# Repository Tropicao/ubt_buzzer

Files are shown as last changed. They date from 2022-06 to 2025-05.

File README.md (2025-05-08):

# Ultimate Blind Test Buzzer

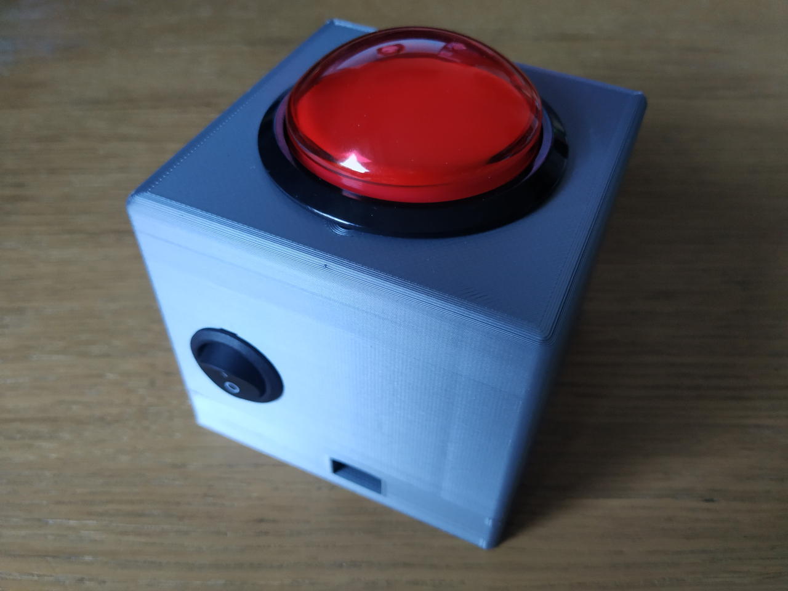
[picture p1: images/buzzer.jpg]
button


## Brief
The Ultimate Blind Test Buzzer (ubt_buzzer) is a companion device for the Ultimate Blind Test. Its main goal
is to provide a basic user interface to allow blind test players to compete.

## Architecture
The buzzer relies on ESP32 with a button connected to it. The buzzer must connect to an access point which offers access to the Ultimate Blind Test server. Once connected, the Ultimate Blind Test server and the buzzer communicate over websocket, for configuration and for statuses (e.g : button pushed)

## Buzzer hardware configuration
* The buzzer is based on ESP32 board with a LiPo charge controller
* A battery can be connected onto the battery controller. Wiring a switch between the two elements allow a simple on/off feature on the buzzer
* The buzzer is meant to be used with a simple push button on GPIO 14 (no need to wire any pull resistor nor RC circuit, button is pulled and debounced by ESP32)

The following layout can be used as an example :
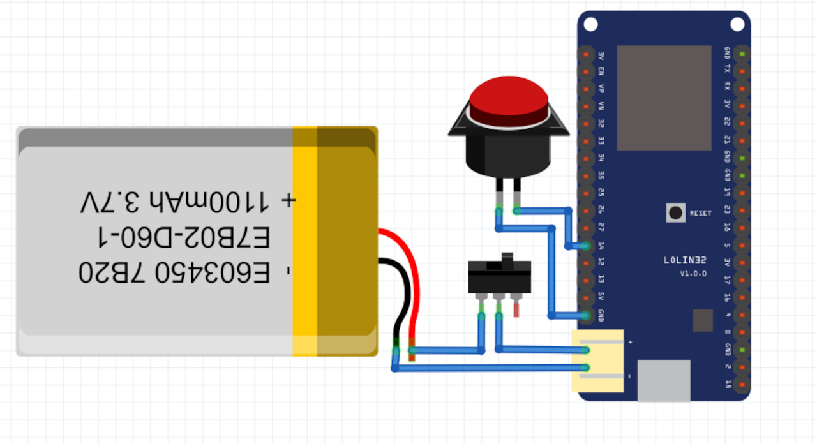
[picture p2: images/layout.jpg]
layout


You can refer to the following components list :
* [AZ-Delivery ESP32 Lolin](https://www.az-delivery.de/fr/products/esp32-lolin-lolin32)
* [Basic Lithium-Polymer battery](https://fr.aliexpress.com/wholesale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), make sure to take a 3.7V battery with connector matching the one on ESP32 board
* [On/Off Switch](https://fr.aliexpress.com/wholesale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)
* [Arcade button](https://fr.aliexpress.com/wholesale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)

## Buzzer sofware configuration
* Install ESP IDF SDK
* activate SDK with `export.sh`
* the project comes with some configuration regarding the controller that
  the buzzer is supposed to connect to:
  - Access point SSID
  - Access point password
  - controller IP address
  - controller port
  If you are using the [default controller
  configuration](https://github.com/Tropicao/ubt_controller), the default
  values should be enough. However, if you want to change those, use
  `idf.py menuconfig` and change the values under the "Buzzer
  configuration" menu. Don't forget to use `idf.py save-defconfig`
  afterward.
* configure your target: there are multiple variants of esp32, and so you
  must build the software for your specific variant. The default is
  `esp32`. You can list available targets with `idf.py --list-targets`, and
  set the target with `idf.py set-target <target>`
* use `idf.py build` to build the project
* plug the buzzer to computer with an USB cable
* use `idf.py flash` to reflash the buzzer
* advanced user : you can use `idf.py monitor` to manage both previous steps and get device logs

## Buzzer network configuration
The project has a default network configuration applied, which can be tuned if needed. You can edit the network configuration by executing `idf.py menuconfig`, then selecting the "Buzzer configuration" menu.

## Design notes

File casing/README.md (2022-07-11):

# Casing

The buzzer can be assembled in a 3D printed casing  :
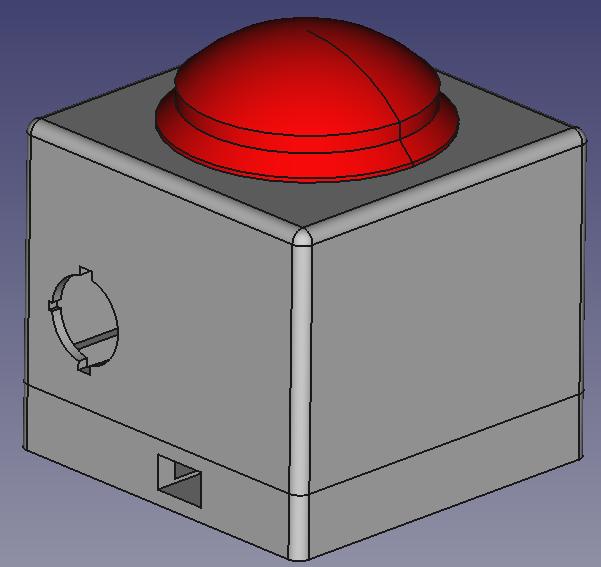
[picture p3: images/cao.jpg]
cao


The provided casing has been designed in [Freecad](https://www.freecadweb.org/). It is composed of two parts. Both can be printed without supports, you only need to print the top part upside-down : 
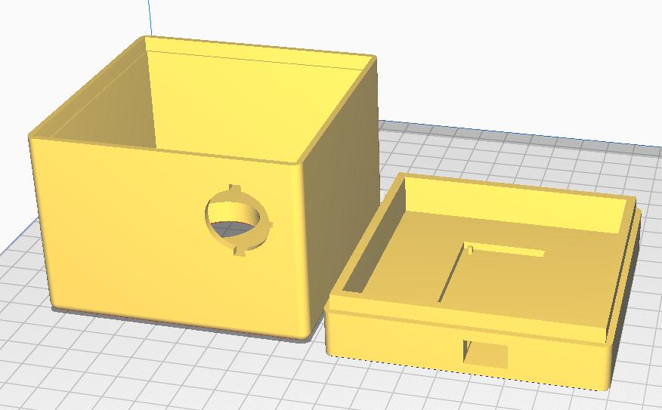
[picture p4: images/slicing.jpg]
slicing


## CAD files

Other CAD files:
casing/ubt_buzzer.FCStd

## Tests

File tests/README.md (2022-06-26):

# Testing UBT Buzzer

This repository contains some tooling and tests to validate UBT buzzer behavior. The main testing component is a basic websocket server, which will log on stdout any message received. To use it : 
* create a virtual environment on your machine : `virtualenv .venv`
* activate the virtual environment : `source .venv/bin/activate`
* install the testing tool dependency : `pip install -r requirements.txt`
* run the tool : `./server.py`

By default, the websocket server will start listening on port 8080

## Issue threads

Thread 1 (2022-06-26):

Debounce button push

Tropicao, 2022-06-26:
Currently, when pressing the button, two messages can go instead of one, due tu wrong button read. UBT Buzzer needs either :
* hardware button debounce, with a properly tailored RC circuit
* software debounce : create a task for button read which ensure that only one push is sent

Closed 2022-07-01.

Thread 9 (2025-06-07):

Improve charging status feedback

Tropicao, 2025-06-07:
It is a bit hard to know if the buzzer charging. For both versions of the buzzer, there is a small led on when it is charging (blue led for the Az Delivery ESP32, red led for the Xiao ESP32), but being on the module, we barely see it through the USB hole on the buzzer side.

It would be better to have a led exposed directly on the casing of the Buzzer, or an info on a small screen.

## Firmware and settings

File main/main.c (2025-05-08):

#include <inttypes.h>
#include "sdkconfig.h"
#include "freertos/FreeRTOS.h"
#include "freertos/task.h"
#include "esp_log.h"
#include "esp_event.h"
#include "ubt_button.h"
#include "ubt_network.h"
#include "common.h"
#include "cJSON.h"
#include "esp_mac.h"

#define TAG "APP"
TaskHandle_t xAppTask = NULL;

static void _send_button_pushed_message(void)
{
    uint8_t u8Address[6] = {0};
    char strAddress[13] = {0};
    char *pcMessage = NULL;
    esp_read_mac(u8Address, ESP_MAC_WIFI_STA);
    snprintf(strAddress, 13, "%02x%02x%02x%02x%02x%02x",
             u8Address[0], u8Address[1], u8Address[2], u8Address[3], u8Address[4], u8Address[5]);
    cJSON *message = cJSON_CreateObject();
    cJSON_AddStringToObject(message, "type", "buzz");
    cJSON_AddStringToObject(message, "id", strAddress);
    pcMessage = cJSON_Print(message);
    cJSON_free(message);
    ubt_network_sendmessage(pcMessage);
    free(pcMessage);
}

static void _send_identify_message(void)
{
    uint8_t u8Address[6] = {0};
    char strAddress[13] = {0};
    char *pcMessage = NULL;
    esp_read_mac(u8Address, ESP_MAC_WIFI_STA);
    snprintf(strAddress, 13, "%02x%02x%02x%02x%02x%02x",
             u8Address[0], u8Address[1], u8Address[2], u8Address[3], u8Address[4], u8Address[5]);
    cJSON *message = cJSON_CreateObject();
    cJSON_AddStringToObject(message, "type", "identification");
    cJSON_AddStringToObject(message, "id", strAddress);
    pcMessage = cJSON_Print(message);
    cJSON_free(message);
    ubt_network_sendmessage(pcMessage);
    free(pcMessage);
}

/**
 * @brief Main task in charge of managing buzzer behaviour
 * The main task listen on its task notifications with the following bits :
 * See common.h for notifications that task is listening to
 * @param pvParameters
 */
static void main_task(void *pvParameters)
{
    uint32_t u32Notification = 0;
    ESP_LOGI(TAG, "Buzzer ready");
    while (true)
    {
        if (xTaskNotifyWait(0, ULONG_MAX, &u32Notification, portMAX_DELAY) == pdFALSE)
        {
            continue;
        }
        ESP_LOGD(TAG, "New notification (%"PRIu32")", u32Notification);
        if (u32Notification & (1 << NOTIFICATION_BUTTON_EVENT))
        {
            ESP_LOGI(TAG, "Button pushed, send notification to server");
            _send_button_pushed_message();
        }
        else if (u32Notification & (1 << NOTIFICATION_NETWORK_UP))
        {
            ESP_LOGI(TAG, "Connected to server, send identification");
            _send_identify_message();
        }
    }
}

void app_main(void)
{
    esp_log_level_set(TAG, ESP_LOG_DEBUG);
    ESP_ERROR_CHECK(esp_event_loop_create_default());
    xTaskCreate(&main_task, "main_task", 4096, NULL, 5, &xAppTask);
    ubt_network_start();
    ubt_button_start();
}

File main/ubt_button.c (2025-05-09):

#include "common.h"
#include "driver/gpio.h"
#include "esp_log.h"
#include "freertos/projdefs.h"
#include "freertos/task.h"
#include "hal/gpio_types.h"
#include "portmacro.h"
#include "sdkconfig.h"

#define TAG "BUTTON"
#define NUM(x) x
#define CONCAT(x,y) x ## y
#define GPIO_APPLY(x, y) CONCAT(x,y)
#define BUTTON_GPIO GPIO_APPLY(GPIO_NUM_, CONFIG_UBT_BUTTON_GPIO)
#define BUTTON_PIN_MASK (1 << CONFIG_UBT_BUTTON_GPIO)
#define BUTTON_DEBOUNCE_DELAY_MS 10

static TaskHandle_t _button_task = NULL;

static void gpio_isr_handler(void *arg);

static esp_err_t configure_button_isr(bool  enable)
{
	return enable ? gpio_isr_handler_add(CONFIG_UBT_BUTTON_GPIO, gpio_isr_handler,
			NULL)
		: gpio_isr_handler_remove(CONFIG_UBT_BUTTON_GPIO);
}

static void _button_task_func(void *pvArg) {
	uint32_t notification;
	int button_state;
	while(true) {
		notification = ulTaskNotifyTake(true, pdMS_TO_TICKS(1000));
		// Timeout, no event occured
		if (!notification)
			continue;

		/* An ISR has triggered: debounce it by waiting a bit, and
		 * then reading the actual value
		 */
		vTaskDelay(pdMS_TO_TICKS(BUTTON_DEBOUNCE_DELAY_MS));
		button_state = gpio_get_level(CONFIG_UBT_BUTTON_GPIO);

		/* If the button is 0 after debounce delay, it is an actual
		 * push: send push notification
		 */
		if (!button_state)
			xTaskNotify(xAppTask, 1 << NOTIFICATION_BUTTON_EVENT, eSetBits);

		/* Whether it is a glitch or an actual button push,
		 * re-enable the button ISR
		 */
		configure_button_isr(true);
	}
}

static void gpio_isr_handler(void *arg)
{
	BaseType_t higher_prio_task_awoken = false;
	/* The ISR could be an actual push, or it could be a glitch
	 * following an actual button movement. While it is not a big deal
	 * if it follows a button push, it is an actual issue if the glitch
	 * follows a button release, so disable ISR to allow debouncing it
	 * (cf button task code)
	 */
	configure_button_isr(false);
	vTaskNotifyGiveFromISR(_button_task, &higher_prio_task_awoken);
}

void ubt_button_start() {
  esp_log_level_set(TAG, ESP_LOG_DEBUG);
  ESP_LOGI(TAG, "Configuring button");
  gpio_config_t config = {.pin_bit_mask = BUTTON_PIN_MASK,
                          .intr_type = GPIO_INTR_NEGEDGE,
                          .mode = GPIO_MODE_INPUT,
                          .pull_up_en = GPIO_PULLUP_ENABLE};
  xTaskCreate(&_button_task_func, "button_task", 4096, NULL, 6, &_button_task);
  ESP_ERROR_CHECK(gpio_config(&config));
  gpio_install_isr_service(0);
  configure_button_isr(true);
  ESP_LOGI(TAG, "Button ready");
}

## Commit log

2022-06-26 Add log from app when buzzer is ready
    [main.c]
2022-06-26 Move button to gpio 14
2022-06-26 Send buzz message when button is pushed
    [main.c]
2022-06-26 Fix buzzer application start management
    [main.c]
2022-06-26 Fix #5 : send identify message on reconnection
    [main.c]
2022-07-01 Fix #1 : poll gpio button instead of using irq, add software debounce
    [ubt_button.c]
2022-07-11 Fix #6 : add hardware and housing instructions
    [layout.fzz, ubt_buzzer.FCStd]
2025-05-08 readme: add instructions to tune buzzer configuration
    Add instructions to change network configuration of the buzzer, in case
    one uses a custom controller or want to use the test setup provided in
    this repository
2025-05-08 readme: add instructions to configure target
    The project currently supports ESP32 by default, but I need to be able
    to build it for XIAO ESP32C3. Add instruction to change the default
    target
2025-05-08 main: fix logging call
    Build fails on an error in the logging macros.
    Use proper logging formatter to fix it.
    [main.c]
2025-05-08 network: improve early setup logging
    Add some logs about the accessed server. Also, interrupt setup if we
    fail to connect.
2025-05-08 config: update default target
    My new default target is esp32c3, update sdkconfig defaults to reflect
    it.
2025-05-08 button: allow to configure button GPIO in project
    Now that multiple variants of ESP32 are supported, it does not make
    sense anymore to hardcode the button gpio in the code (the current
    hardcoded GPIO isn't even exposed on Xiao ESP32C3).
    Set the GPIO number as a project configuration. Set the default value
    relevant for Xiao ESP32C3 (button wired on pin D0)
2025-05-08 button: use FreeRTOS helper for delay computation
    Instead of manually performing the task delay computation, use
    pdMS_TO_TICKS.
2025-05-08 button: add task delete
    Add vTaskDelete for proper cleanup if the task has to stop for any
    reason
2025-05-08 button: do not start polling task before having configured GPIO
    It does not make sense to start polling the button if we haven't even
    configured the corresponding GPIO.
    Start task only after having configured the button GPIO.
2025-05-08 button: reduce polling frequency
    The current polling frequency can even starve the idle task watchdog
2025-05-08 button: adjust log
    Update log to really reflect the fact that it is ready.
2025-05-09 button: replace polling with proper interrupt-driven push detect
    The application is currently polling (pretty aggressively) the button
    state to detect a button push. Replace the whole logic with a proper
    interrupt driven logic.
    The button is pretty noisy considering its electrical properties: it
    triggers multiple interrupts when pressing it, and it also trigger
    interrupts when releasing the button, even if the interrupt is
    configured as falling edge. ESP32 chips integrate two types of filters
    to help with this, but it appears inneficient in the buzzer case:
    - a simple "pin glitch filter" which is not configurable: it will filter
    glitches that are shorter than 2 ticks, and so it does not m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
    [ubt_button.c]
